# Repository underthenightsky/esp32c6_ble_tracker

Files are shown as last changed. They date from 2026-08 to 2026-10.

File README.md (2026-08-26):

# ESP32-C6 BLE Tracker — Low-Power / IMU-Gated Edition

Targets roughly **10 days on a 1000mAh battery** for an asset that
moves ~2 hrs/day, by only running BLE/WiFi when something's actually
happening — not on a fixed timer.

## Trade-off vs the other firmware variants

This version does **not** serve its own local web page. It's asleep
almost all the time, so it can't reliably answer HTTP requests — it
only pushes to your `ble_tracker_server`. If you want the
always-reachable local page, use `esp32_ble_tracker` (or
`particle_ble_tracker`) instead. You can't have both always-on local
browsability and this level of battery life on the same design — the
whole power saving comes from the radios being off almost all the
time.

## How it works

**Stationary** (the default state):
- Deep sleep, ~10 µA
- LIS3DH accelerometer armed for wake-on-motion, ~2-5 µA
- Nothing scans, nothing transmits — total draw ~15 µA
- Optional heartbeat (`HEARTBEAT_INTERVAL_S`, default 15 min): wakes
  briefly to re-push the last known position so your dashboard's
  "last seen" doesn't go stale for hours during a long stationary
  spell. Cheap since it's infrequent and skips the BLE scan entirely.

**Moving** (triggered by the IMU's motion interrupt):
- BLE scan burst (`SCAN_BURST_MS`, ~4-5s) → one-shot position estimate
- Moved ≥ `MOVE_THRESHOLD_M` (default 5m) since the last push? →
  connect WiFi, push to the server
- Didn't move that far? → skip WiFi entirely this cycle
- Re-checks every `ACTIVE_INTERVAL_S` (10s) using **light sleep**
  between cycles, which preserves the WiFi association — so a
  continuously-moving asset doesn't pay a full reconnect cost every
  10 seconds, just periodic scan+push bursts
- After `MAX_STATIONARY_CONFIRMS` (default 3, ~30s) consecutive
  checks with no real movement, drops WiFi and returns to deep,
  IMU-gated sleep

## Hardware

- ESP32-C6 dev board
- LIS3DH accelerometer breakout (I2C)
- Wiring:
  - LIS3DH SDA/SCL → ESP32-C6 I2C pins
  - LIS3DH INT1 → `IMU_INT_GPIO` in the `.ino` (default `GPIO_NUM_3`)
    — **this must be GPIO0–7**, the only pins in the C6's LP/RTC
    domain that can wake it from deep sleep. This is a hardware
    constraint of the chip, not something you can change in software.
  - LIS3DH VIN/GND → same 3.3V rail as the ESP32

No accelerometer library needed — `imu_lis3dh.h` is a small hand-
rolled I2C register driver (the LIS3DH's register map is simple and
well-documented, so this avoids pulling in a full library for what's
really about 8 register writes).

## Libraries

Just **NimBLE-Arduino** (h2zero, tested with 2.x). Everything else
(WiFi, HTTPClient, deep/light sleep) is core to the ESP32 Arduino
package — make sure you have a recent-enough `arduino-esp32` core
version with ESP32-C6 support.

## Configure

At the top of the `.ino`:

```cpp
const char* WIFI_SSID       = "YOUR_WIFI_SSID";
const char* WIFI_PASS       = "YOUR_WIFI_PASSWORD";
const char* SERVER_HOST     = "https://tracker.yourdomain.com";
const char* SERVER_API_KEY  = "changeme";      // matches server's BLE_TRACKER_API_KEY
const char* DEVICE_ID       = "esp32c6-01";    // unique per device
```

And in `imu_lis3dh.h`, `LIS3DH_ADDR` (0x18 or 0x19 depending on your
board's SA0 pin state) and `LIS3DH_MOTION_THRESHOLD` (how firm a nudge
is needed to trigger a wake — lower = more sensitive/more frequent
wakes, higher = fewer false wakes but might miss gentle movement).

## The 10-day estimate — read this before you commit to a battery

| Period | Current | Basis |
|---|---|---|
| Stationary (deep sleep + IMU armed) | ~15 µA | Published ESP32-C6 deep sleep (~10µA) + LIS3DH standby (~2-5µA) figures |
| Moving (BLE scan + WiFi, light-sleep between cycles) | ~40-50 mA avg | Estimated from published component figures — WiFi connected+modem-sleep, BLE scan burst duty-cycled over the 10s active interval |

At 2 hrs/day moving: **~85-100 mAh/day → ~10-11 days on 1000mAh**
(before real-world derating for regulator efficiency and battery
discharge curve, which typically costs another 10-15%).

**This is a directional estimate, not a bench measurement of your
specific board.** The biggest source of uncertainty is the "moving"
state average current — it depends heavily on your WiFi AP's DTIM
interval, signal strength, and exactly how well light-sleep preserves
the WiFi association on your specific core version. Before finalizing
a battery/enclosure:

1. Flash this firmware and measure actual current draw with a
   multimeter (in series with the battery) or a USB power profiler,
   in both states
2. Adjust `ACTIVE_INTERVAL_S`, `MAX_STATIONARY_CONFIRMS`,
   `HEARTBEAT_INTERVAL_S`, and `LIS3DH_MOTION_THRESHOLD` based on what
   you actually measure and how the trade-off between battery life
   and tracking responsiveness feels for your use case
3. Re-run the math with your measured numbers before ordering
   batteries for a fleet of these

## Tuning cheat sheet

| Constant | Effect of increasing it |
|---|---|
| `MOVE_THRESHOLD_M` | Fewer pushes, more battery life, coarser tracking |
| `ACTIVE_INTERVAL_S` | Fewer scan/push cycles while moving, more battery life, less responsive tracking |
| `MAX_STATIONARY_CONFIRMS` | Longer before dropping back to deep sleep after motion stops, more conservative about "really stopped" |
| `HEARTBEAT_INTERVAL_S` | Less frequent stationary check-ins, better battery life, staler "last seen" during long idle periods |
| `LIS3DH_MOTION_THRESHOLD` | Firmer nudge needed to wake, fewer false wakes, might miss gentle movement |

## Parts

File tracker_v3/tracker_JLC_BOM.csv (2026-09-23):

Comment | Designator | Footprint | JLCPCB Part #
Battery_Cell | BT1 | JST PH 2-pin, 2.00mm, right-angle THT
100n | C1,C3,C7 | 0603
10u | C2,C5,C6 | 0603
LED | D1,D2 | 0603
USB_C_Receptacle_PowerOnly_6P | J1 | USB-C receptacle, power-only 6P
DMG9926UDM-7 | Q1 | SOT-26 | C156289
0.1 | R1 | 2512
680 | R10,R8 | 0603
4.7k | R2,R3 | 0603
1.2k | R4 | 0603
5.1k | R5,R6 | 0603
100 | R7 | 0603
1k | R9 | 0603
XIAO-ESP32-C6-SMD | U1 | Seeed XIAO ESP32-C6 module
LIS3DH | U2 | LGA-16
DW01A | U3 | SOT-23-6 | C2927799
INA226AIDGSR | U4 | MSOP-10 | C49851
TP4056-42-ESOP8 | U5 | ESOP-8 | C16581

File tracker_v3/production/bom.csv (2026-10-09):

Designator | Footprint | Quantity | Value | LCSC Part #
BT1 | JST_PH_S2B-PH-K_1x02_P2.00mm_Horizontal | 1 | Battery_Cell
C1, C3, C7 | 0603 | 3 | 100n
C2, C5, C6 | 0603 | 3 | 10u
D1, D2 | 0603 | 2 | LED
J1 | USB_C_Receptacle_GCT_USB4125-xx-x-0190_6P_TopMnt_Horizontal | 1 | USB_C_Receptacle_PowerOnly_6P
J2, J3 | HARWIN_P70-7000045 | 2 | P70-7000045
Q1 | SOT-26_DIO | 1 | DMG9926UDM-7
R1 | 2512 | 1 | 0.1
R10, R8 | 0603 | 2 | 680
R2, R3 | 0603 | 2 | 4.7k
R4 | 0603 | 1 | 1.2k
R5, R6 | 0603 | 2 | 5.1k
R7 | 0603 | 1 | 100
R9 | 0603 | 1 | 1k
TP1, TP2, TP3, TP4, TP5, TP6, TP7, TP8 | TestPoint_Pad_D1.0mm | 8 | TestPoint
U1 | XIAO-ESP32-C6-DIP | 1 | XIAO-ESP32-DIP
U2 | LGA-16_3x3mm_P0.5mm_LayoutBorder3x5y | 1 | LIS3DH
U3 | SOT-23-6 | 1 | DW01A
U4 | MSOP-10_3x3mm_P0.5mm | 1 | INA226AIDGSR | C49851
U5 | SOIC-8-1EP_3.9x4.9mm_P1.27mm_EP2.41x3.3mm_ThermalVias | 1 | TP4056-42-ESOP8

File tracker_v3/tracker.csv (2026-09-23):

Designator | Footprint | Quantity | Designation | Supplier and ref
BT1 | JST_PH_S2B-PH-K_1x02_P2.00mm_Horizontal | 1 | Battery_Cell
C1, C3, C7 | C_0603_1608Metric | 3 | 100n
C2, C5, C6 | C_0603_1608Metric | 3 | 10u
D1, D2 | LED_0603_1608Metric | 2 | LED
J1 | USB_C_Receptacle_GCT_USB4125-xx-x-0190_6P_TopMnt_Horizontal | 1 | USB_C_Receptacle_PowerOnly_6P
Q1 | SOT-26_DIO | 1 | DMG9926UDM-7
R1 | R_2512_6332Metric | 1 | 0.1
R2, R3 | R_0603_1608Metric | 2 | 4.7k
R4 | R_0603_1608Metric | 1 | 1.2k
R5, R6 | R_0603_1608Metric | 2 | 5.1k
R7 | R_0603_1608Metric | 1 | 100
R8, R10 | R_0603_1608Metric | 2 | 680
R9 | R_0603_1608Metric | 1 | 1k
U1 | XIAO-ESP32-C6-SMD | 1 | XIAO-ESP32-C6-SMD
U2 | LGA-16_3x3mm_P0.5mm_LayoutBorder3x5y | 1 | LIS3DH
U3 | SOT-23-6 | 1 | DW01A
U4 | MSOP-10_3x3mm_P0.5mm | 1 | INA226AIDGSR
U5 | SOIC-8-1EP_3.9x4.9mm_P1.27mm_EP2.41x3.3mm_ThermalVias | 1 | TP4056-42-ESOP8

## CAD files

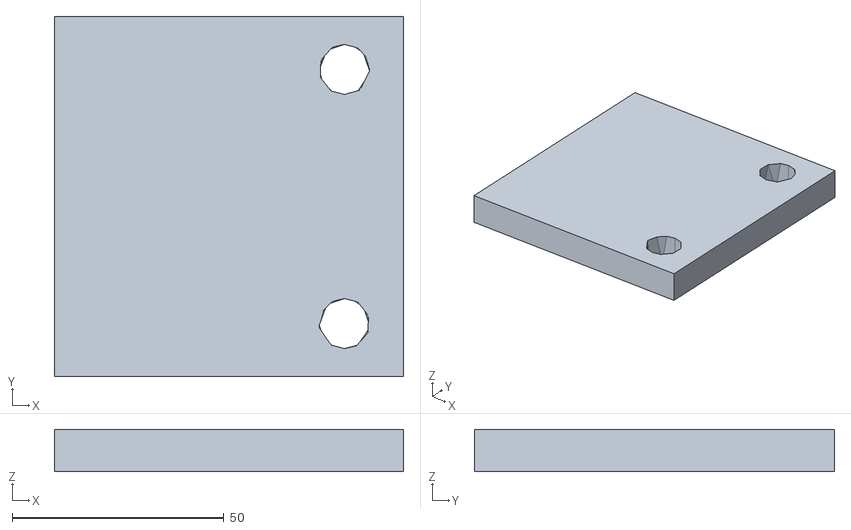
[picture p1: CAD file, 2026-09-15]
tracker_v3/OBJ_INA226-CJMCU-226-BLUE_2026-09-15/OBJ_INA226 CJMCU-226 BLUE.obj
82.5 x 85.0 x 10.0

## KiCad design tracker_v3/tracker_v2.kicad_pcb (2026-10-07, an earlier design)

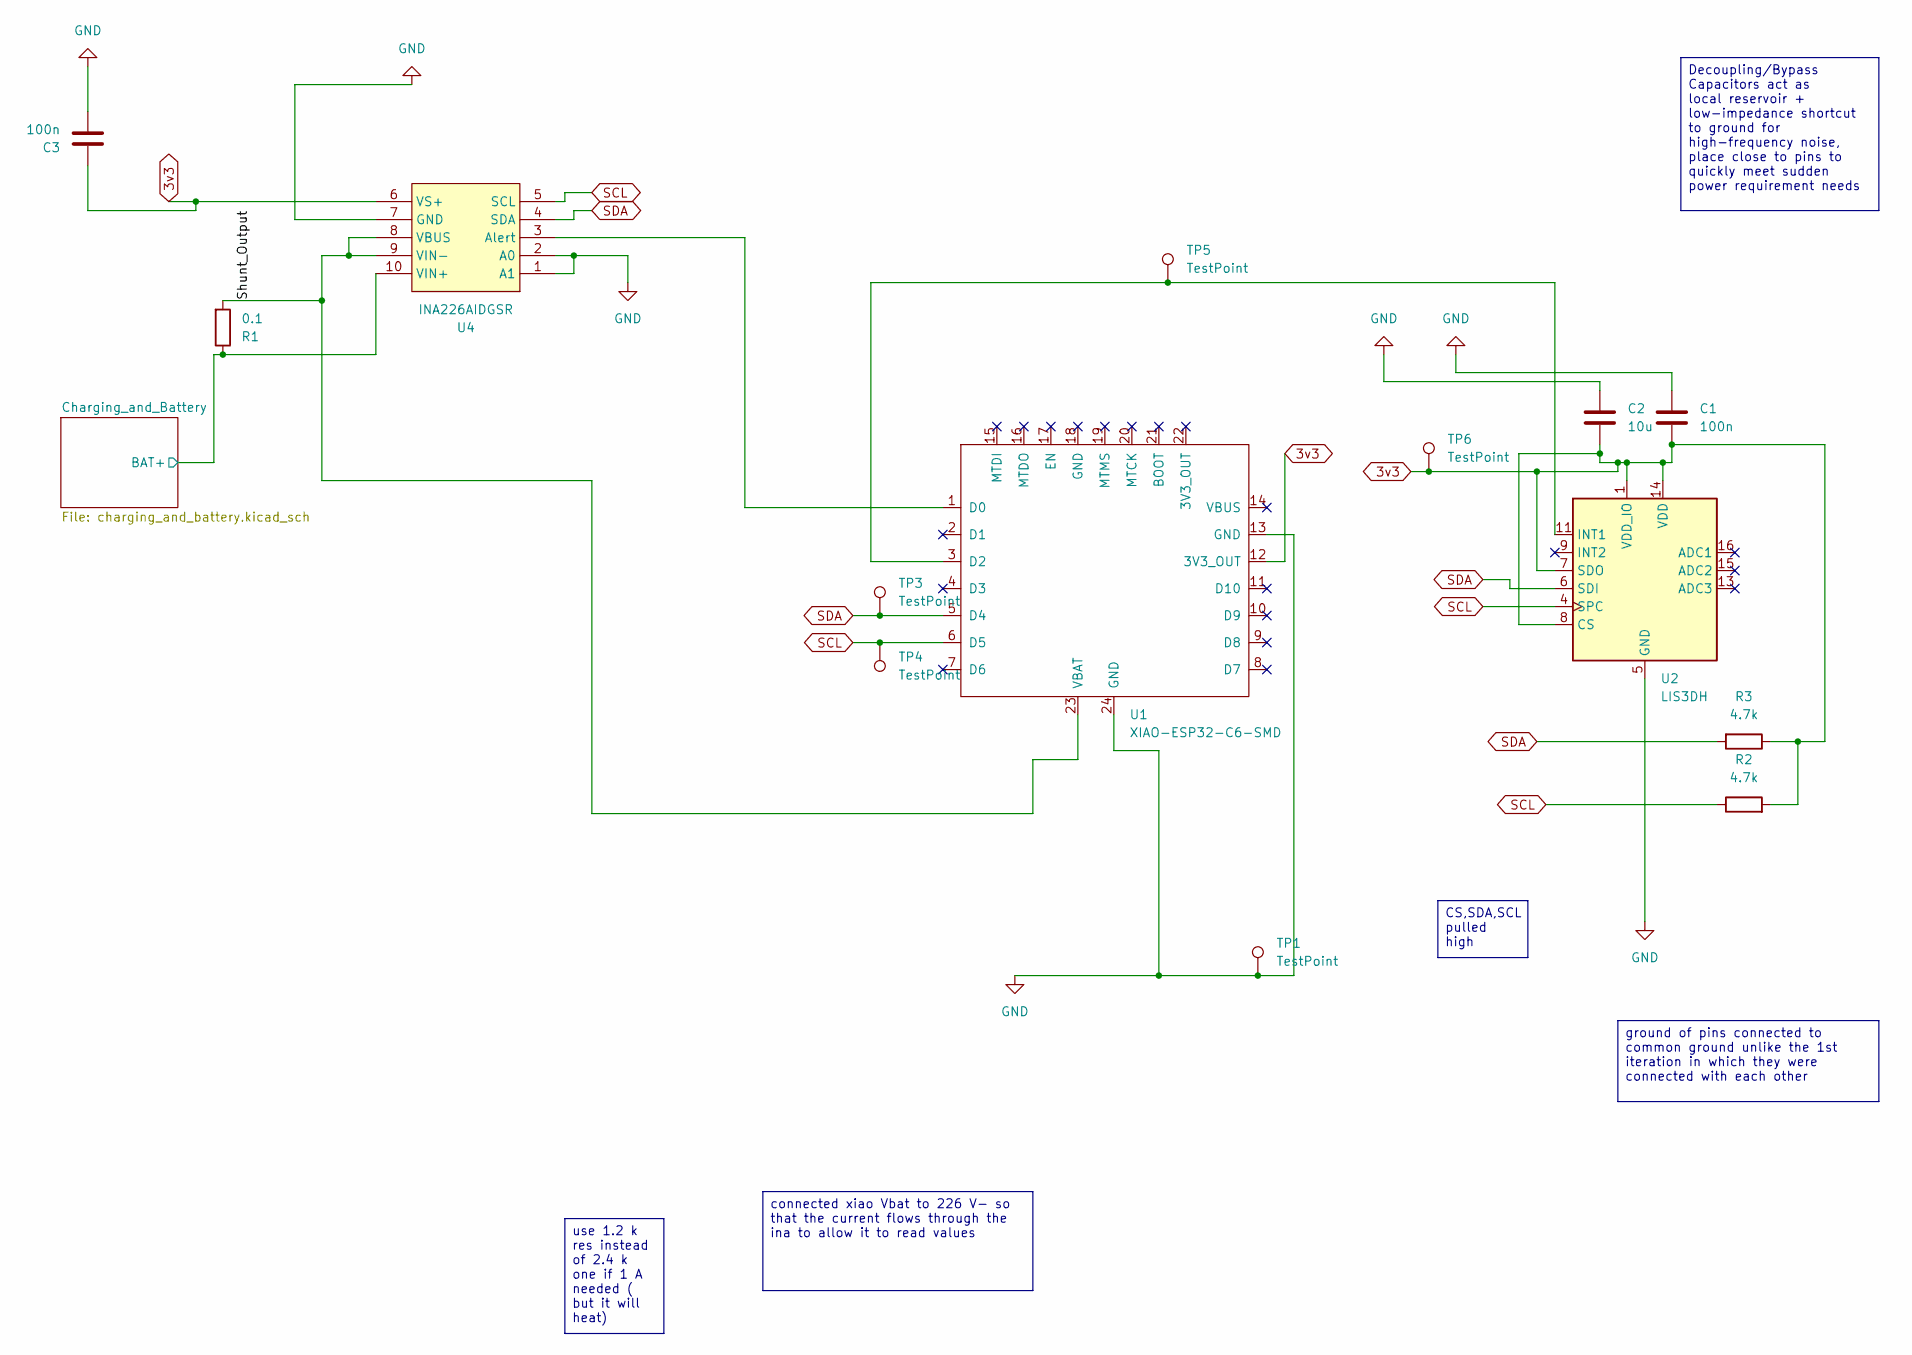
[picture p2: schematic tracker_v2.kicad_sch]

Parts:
C1, C3: 100n; C_0603_1608Metric
C2: 10u; C_0603_1608Metric
R1: 0.1; R_2512_6332Metric
R2, R3: 4.7k; R_0603_1608Metric
TP1, TP3, TP4, TP5, TP6: TestPoint; TestPoint_Pad_D1.0mm
U1: XIAO-ESP32-C6-SMD
U2: LIS3DH; LGA-16_3x3mm_P0.5mm_LayoutBorder3x5y
U4: INA226AIDGSR; MSOP-10_3x3mm_P0.5mm; MPN INA226AIDGSR; LCSC Part C49851

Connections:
3v3: C1.2, C2.2, C3.1, R2.2, R3.1, TP6.1 (1_1), U1.12 (3V3_OUT), U2.1 (VDD_IO), U2.7 (SDO), U2.8 (CS), U2.14 (VDD), U4.6 (VS+)
/Charging_and_Battery/BAT+: R1.1, U4.10 (VIN+); also elsewhere on the board
/Shunt_Output: R1.2, U1.23 (VBAT), U4.8 (VBUS), U4.9 (VIN-)
GND: C1.1, C2.1, C3.2, TP1.1 (1_1), U1.13 (GND), U1.24 (GND), U2.5 (GND), U2.10 (GND), U2.12 (GND), U4.1 (A1), U4.2 (A0), U4.7 (GND); also elsewhere on the board
unnamed: U1.1 (D0), U4.3 (Alert)
unnamed: TP5.1 (1_1), U1.3 (D2), U2.11 (INT1)
SCL: R2.1, TP4.1 (1_1), U1.6 (D5), U2.4 (SPC), U4.5 (SCL)
SDA: R3.2, TP3.1 (1_1), U1.5 (D4), U2.6 (SDI), U4.4 (SDA)

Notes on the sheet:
CS,SDA,SCL pulled high
connected xiao Vbat to 226 V- so that the current flows through the ina to allow it to read values
ground of pins connected to common ground unlike the 1st iteration in which they were connected with each other
Decoupling/Bypass Capacitors act as local reservoir + low-impedance shortcut to ground for high-frequency noise, place close to pins to quickly meet sudden power requirement needs
use 1.2 k res instead of 2.4 k one if 1 A needed ( but it will heat)

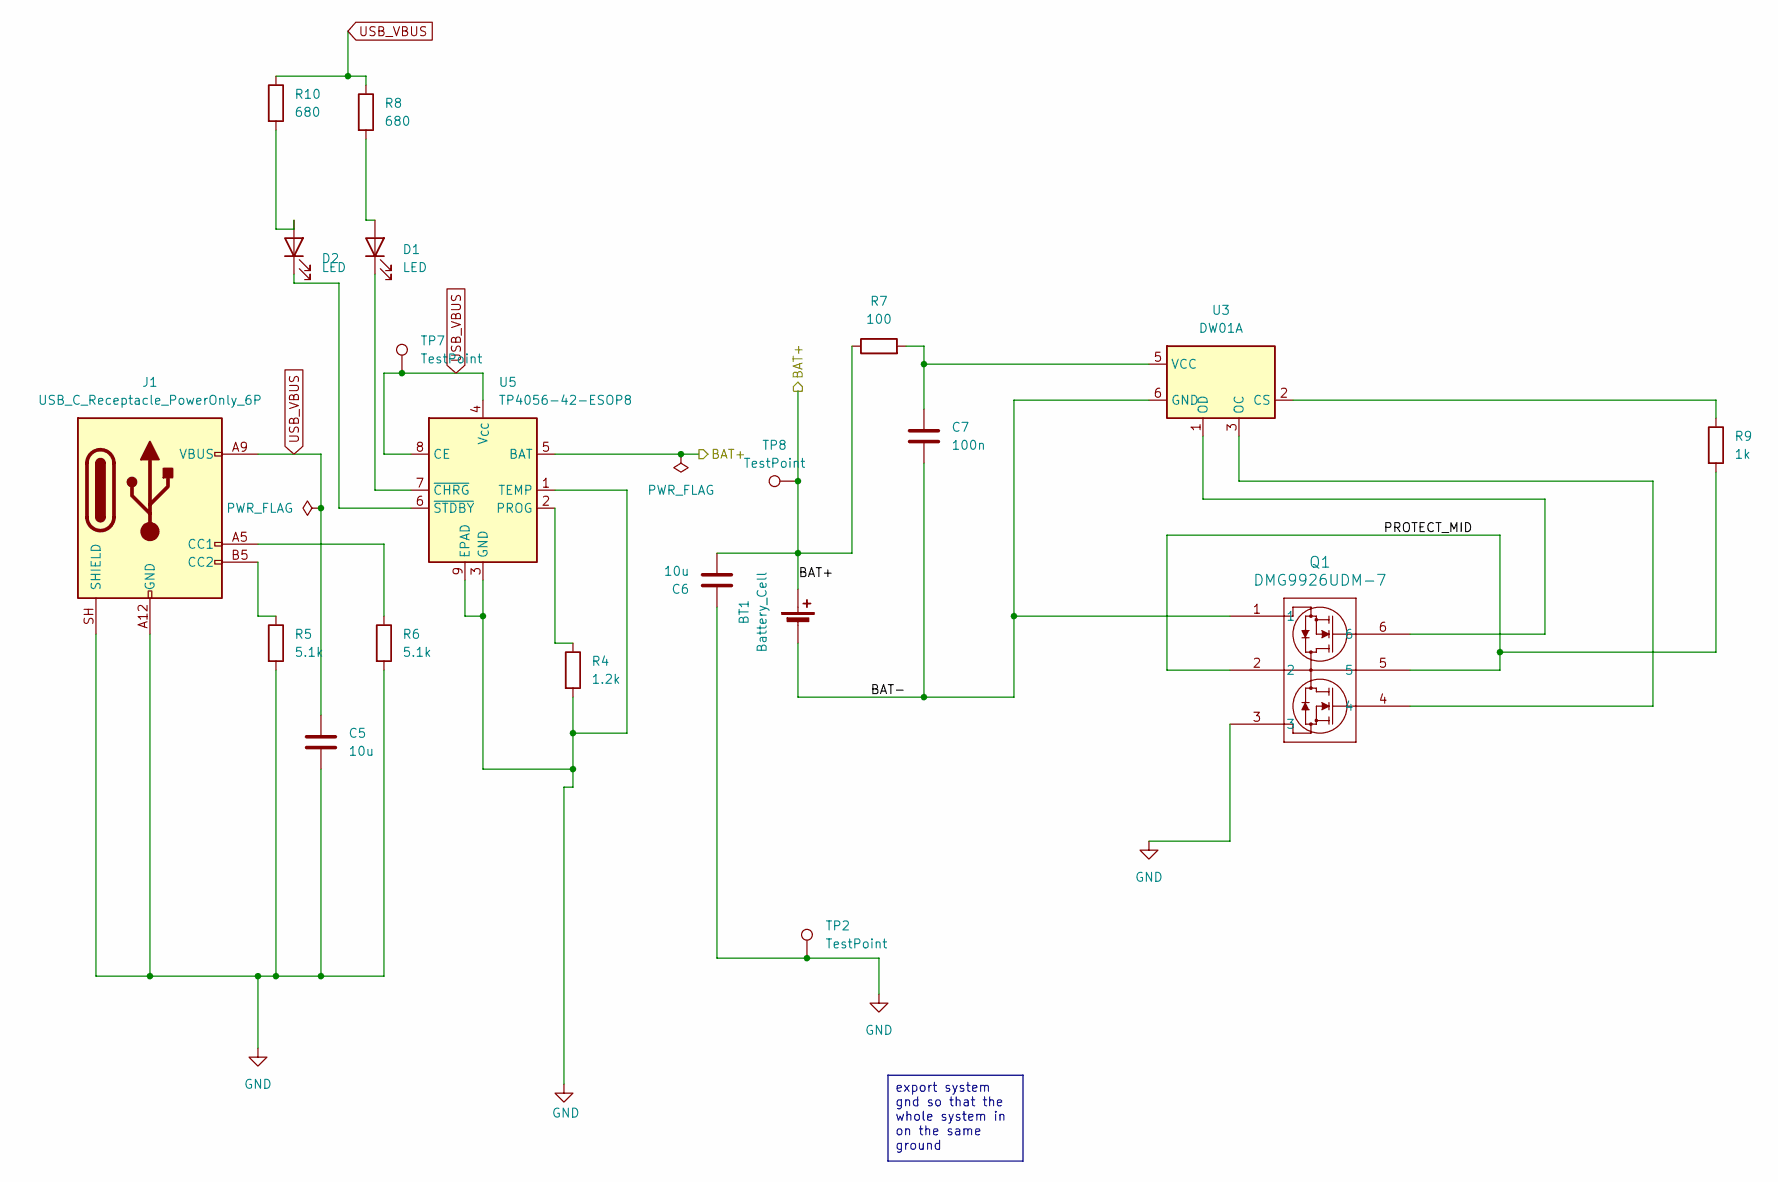
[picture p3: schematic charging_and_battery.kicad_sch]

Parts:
BT1: Battery_Cell; JST_PH_S2B-PH-K_1x02_P2.00mm_Horizontal
C5, C6: 10u; C_0603_1608Metric
C7: 100n; C_0603_1608Metric
D1, D2: LED; LED_0603_1608Metric
J1: USB_C_Receptacle_PowerOnly_6P; USB_C_Receptacle_GCT_USB4125-xx-x-0190_6P_TopMnt_Horizontal
Q1: DMG9926UDM-7; SOT-26_DIO
R4: 1.2k; R_0603_1608Metric
R5, R6: 5.1k; R_0603_1608Metric
R7: 100; R_0603_1608Metric
R8, R10: 680; R_0603_1608Metric
R9: 1k; R_0603_1608Metric
TP2, TP7, TP8: TestPoint; TestPoint_Pad_D1.0mm
U3: DW01A; SOT-23-6
U5: TP4056-42-ESOP8; SOIC-8-1EP_3.9x4.9mm_P1.27mm_EP2.41x3.3mm_ThermalVias

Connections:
/Charging_and_Battery/BAT+: BT1.1 (+), C6.2, R7.1, TP8.1 (1_1), U5.5 (BAT); also elsewhere on the board
/Charging_and_Battery/BAT-: BT1.2 (-), C7.2, Q1.1, U3.6 (GND)
/Charging_and_Battery/PROTECT_MID: Q1.2, Q1.5, R9.2
GND: C5.2, C6.1, J1.A12 (GND), J1.B12 (GND), J1.SH (SHIELD), Q1.3, R4.2, R5.2, R6.2, TP2.1 (1_1), U5.1 (TEMP), U5.3 (GND), U5.9 (EPAD); also elsewhere on the board
unnamed: D1.2 (A), R8.2
unnamed: D1.1 (K), U5.7 (~CHRG)
unnamed: D2.2 (A), R10.2
unnamed: D2.1 (K), U5.6 (~STDBY)
unnamed: J1.A5 (CC1), R6.1
unnamed: J1.B5 (CC2), R5.1
unnamed: R9.1, U3.2 (CS)
unnamed: Q1.4, U3.3 (OC)
unnamed: Q1.6, U3.1 (OD)
unnamed: C7.1, R7.2, U3.5 (VCC)
unnamed: R4.1, U5.2 (PROG)
USB_VBUS: C5.1, J1.A9 (VBUS), J1.B9 (VBUS), R8.1, R10.1, TP7.1 (1_1), U5.4 (V_{CC}), U5.8 (CE)

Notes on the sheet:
export system gnd so that the whole system in on the same ground

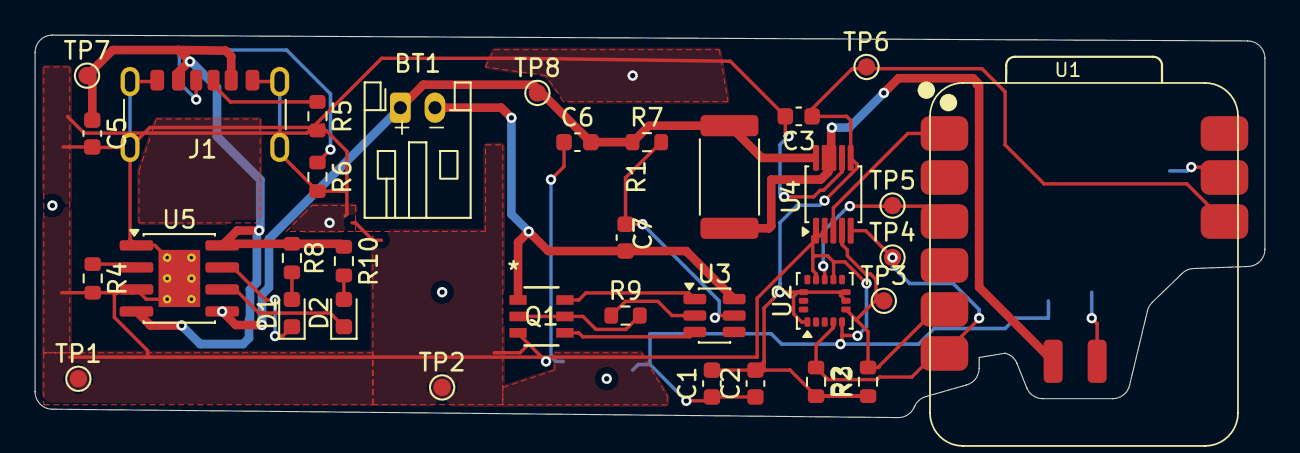
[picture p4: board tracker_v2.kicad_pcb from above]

Board: 2 copper layers, 71.0 x 22.1 mm, 34 parts (0 on the bottom side), 22 nets.

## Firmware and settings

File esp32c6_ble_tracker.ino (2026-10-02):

/*
  MotionWakeSimpleTest.ino — minimal wake-on-motion -> BLE scan -> WiFi push
  (power-optimized variant)

  Deliberately simple, for testing the pipeline end to end:
    1. Deep sleep. LIS3DH wakes it on motion (D2).
    2. On wake: scan for nearby BLE devices for a few seconds (this
       will pick up your phone if its Bluetooth is on — phones usually
       show up as an anonymous rotating address rather than a name,
       which is fine, you can still watch its RSSI change as you move
       it closer/farther. If you want it to show up with a real name,
       install a free app like "nRF Connect" and use its BLE
       peripheral/advertiser feature to broadcast a named signal).
    3. Connect WiFi, POST the scan results (device list + one fresh
       accel reading) to your laptop as one JSON blob.
    4. Go straight back to deep sleep. No loop, no re-checking, no
       "did it really stop moving" state machine — one wake, one
       scan, one push, one sleep. If it's not going back to sleep,
       the bug is much easier to find in this shape than in the full
       tracker's active-loop logic.

  No beacons.h / estimator_types.h dependency — this doesn't do
  position triangulation at all, just reports what it saw.

  Wiring (confirmed): SDA->D4 (GPIO22), SCL->D5 (GPIO23),
  LIS3DH I1 -> D2 (GPIO2, in the C6's LP/RTC wake domain).
  Libraries: SparkFun LIS3DH, NimBLE-Arduino.

  --- POWER CHANGES vs. original ---
  1. LIS3DH ODR dropped 10Hz -> 1Hz (CTRL_REG1 0x2F -> 0x1F). The
     LPen (low-power) bit was already set, so this doesn't change
     operating mode, only sample rate. Adds up to ~1s of wake
     latency worst-case; bump back to 0x2F (10Hz) if that feels
     sluggish in testing.
  2. Added isolateUnusedPins(): on the ESP32-C6, only GPIO0-7 are in
     the LP_IO domain that stays powered for GPIO wakeup (RTC_PERIPH
     stays on for D2), so those are the only pins where a stray
     pull can leak current in deep sleep. D0/D1 are unused here, so
     they get isolated. D3/D6-D10 live in the HP GPIO domain, which
     is fully powered off in deep sleep regardless of firmware —
     nothing to isolate there.
  3. No change needed on the LIS3DH side beyond ODR: LPen was
     already enabled, and full power-down isn't usable since it
     would also disable the wake interrupt.
  4. Added phase timing: millis() timestamps at each stage boundary,
     printed as a table right before deep sleep. Everything from
     "sensor read" onward is measured exactly. Wake+boot latency
     (interrupt -> setup() actually running) can't be measured this
     way -- millis() itself resets at boot -- so WAKE_MARKER_PIN
     (D6, unused) is driven HIGH as the very first line of setup()
     and LOW right before sleep, so that latency shows up directly
     on a scope or power profiler (e.g. Nordic PPK2) against the
     current trace instead of being guessed at.

  Note: XIAO ESP32C6 boards measure ~15uA bare deep-sleep current
  (dominated by the onboard LDO's own quiescent draw per community
  teardown measurements) — the LIS3DH in low-power mode typically
  adds a few uA on top of that per its datasheet. These firmware
  changes get you close to that floor; going lower generally means
  a different/lower-Iq regulator on the board itself, which is a
  hardware change, not a firmware one.
*/

#include "SparkFunLIS3DH.h"
#include "Wire.h"
#include <esp_sleep.h>
#include <WiFi.h>
#include <NimBLEDevice.h>
#include <HTTPClient.h>
#include "driver/rtc_io.h"
#include <INA226_WE.h>
#include "beacons.h"
#include "estimator_types.h"
#include <sys/time.h>
#include "power_meter.h"

// ── WiFi / local test server ────────────────────────────────────────
const char* WIFI_SSID       = "Airtel_Iwayplus";
const char* WIFI_PASS       = "sulpyawi";
const char* SERVER_HOST = "https://esp32c6-ble-tracker.onrender.com";  // was .250
const char* SERVER_API_KEY  = "f4d0cb00-dbf5-11f0-bd35-dd4e9bf51317";
const char* DEVICE_ID       = "esp32-01";

#define LIS3DH_MOTION_THRESHOLD 0x6  // MIDDLE GROUND: ~96mg ( 0x6), a firm tap/nudge triggers it,
                                        // but not every tiny desk vibration.

                                        // Production value was 0x10 (~256mg). Raise back toward
                                        // that once testing is done, if it's too sensitive in use.

// CTRL_REG1: ODR[3:0] | LPen | Zen | Yen | Xen
//   0x2F = 10Hz, low-power mode, all axes  (previous value)
//   0x1F =  1Hz, low-power mode, all axes  (current — lower sample rate,
//           same low-power mode, adds up to ~1s worst-case wake latency)
#define LIS3DH_CTRL_REG1_VALUE 0x1F

// INA226 connection code
// I2C address for INA226 is 0x40
#define I2C_INA226_ADDRESS 0x40

// Timing instrumentation ----------------------------------------------------
// WAKE_MARKER_PIN is toggled HIGH as the very first line of setup() and LOW
// right before esp_deep_sleep_start(). It's unused elsewhere on this board,
// so probing it with a scope or power profiler lines up the exact moment
// code execution starts against the current-draw trace -- the only way to
// see true wake+boot latency, since millis() resets at boot and can't
// measure anything before setup() runs.
#define WAKE_MARKER_PIN D6

#define SCAN_MS 1000              // how long to listen for BLE devices, set to 1500 or higher (not above 2500 to avoid high power drain) for better chances of locating the beacons and calculating the position

const float TEMP =3.0f;
static const int TOP_N =3;
static const float ALPHA_W =0.55f;
static const float BONUS =0.5f;
static const int MIN_RSSI = -110;
// not sure why there is max signal strength limit
// shouldnt stronger signal lead to more confident result ?
static const int MAX_RSSI =-55;

LIS3DH SensorOne(I2C_MODE, 0x19);
RTC_DATA_ATTR uint32_t g_bootCount = 0;
// Persistent estimator memory
// (so that we can compare currently estimated position with previous poistion and 
// decide wether to send the data or not  )
RTC_DATA_ATTR bool g_haveEma = false;
RTC_DATA_ATTR float g_emaX=0,g_emaY=0;
RTC_DATA_ATTR int8_t g_top2[2] {-1,-1};
RTC_DATA_ATTR uint32_t g_tooCloseCount =0;

static const float MOVE_THRESHOLD_M =2.0f;
// last position actually pushed to the server - distict
//from g_emaX/g_emaY above. This is what MOVE_THRESHOLD_M compares against
RTC_DATA_ATTR bool g_havePub = false;
RTC_DATA_ATTR float g_pubX=0, g_pubY =0;

// to check number of wakeups vs number of wifi pushes
RTC_DATA_ATTR uint32_t g_wakeCount = 0;
RTC_DATA_ATTR uint32_t g_noBeaconCount = 0;
RTC_DATA_ATTR uint32_t g_wifiFailCount = 0;
RTC_DATA_ATTR uint32_t g_pushOkCount = 0;

// Per-cycle phase timestamps. Plain (non-RTC) globals on purpose -- deep
// sleep is a full chip reset, so these zero out every boot, giving a clean
// per-cycle timing log instead of an accumulating total.
static unsigned long g_tBoot = 0;
static unsigned long g_tSensorReady = 0;
static unsigned long g_tBleDone = 0;
static unsigned long g_tPosDone = 0;
static unsigned long g_tWifiDone = 0;      // 0 if WiFi step was skipped/never finished
static unsigned long g_tPushDone = 0;      // 0 if push never happened this cycle

// Single Burst aggregated beacon readings
struct Agg{
  bool present = false;
  int peak = -200;
  int n =0;
  float pen_peak =0;
  float score=0;
};

static Agg g_agg[NUM_BEACONS];

// we are making our own class called ScanCallbacks
class ScanCallbacks : public NimBLEScanCallbacks {
  void onResult(const NimBLEAdvertisedDevice* dev) override {

  std::string name = dev->getName();
  // now we get the rssi and later return if the value exceeds the limits
  int rssi = dev->getRSSI();

  if(rssi <= MIN_RSSI ){
    return;
  }
  //now checking against the known beacons name
  for(int i =0; i<NUM_BEACONS;i++){
    if(name == BEACONS[i].name){
      g_agg[i].present = true;
      if(rssi > g_agg[i].peak){
        g_agg[i].peak = rssi;
      }

      g_agg[i].n++ ;
      return;
    }
  }
  }
};
static ScanCallbacks g_scanCallbacks;

// ── LIS3DH motion-interrupt setup (same as the confirmed-working test) ─
static void armMotionInterrupt() {
  SensorOne.writeRegister(LIS3DH_CTRL_REG1, LIS3DH_CTRL_REG1_VALUE);
  SensorOne.writeRegister(LIS3DH_CTRL_REG2, 0x2F);

  // Reading REFERENCE resets the HPF's internal reference to whatever
  // the current (post-filter) value is. Without this, the filter needs
  // several ODR cycles to settle after being (re)enabled, and during
  // that window it can output a transient big enough to cross the
  // threshold by itself -- which looks exactly like a phantom wake
  // with the board sitting perfectly still.
  uint8_t ref;
  SensorOne.readRegister(&ref, LIS3DH_REFERENCE);
  delay(150); // let the filter fully settle before arming/clearing
// was 100ms for 10Hz, at 1Hz we set 1000ms
  SensorOne.writeRegister(LIS3DH_CTRL_REG3, 0x40);
  SensorOne.writeRegister(LIS3DH_CTRL_REG4, 0x00);
  SensorOne.writeRegister(LIS3DH_CTRL_REG5, 0x08);
  SensorOne.writeRegister(LIS3DH_INT1_THS, LIS3DH_MOTION_THRESHOLD);
  SensorOne.writeRegister(LIS3DH_INT1_DURATION, 0x00);
  SensorOne.writeRegister(LIS3DH_INT1_CFG, 0x2A);
}

static void clearMotionInterrupt() {
  uint8_t dummy;
  // Read INT1_SRC in a loop until physical pin drops LOW
  for (int i = 0; i < 10; i++) {
    SensorOne.readRegister(&dummy, LIS3DH_INT1_SRC);
    if (digitalRead(D2) == LOW) break;
    delay(20);
  }
}

// Isolate the GPIOs we don't use that actually matter for deep-sleep
// current on the C6: GPIO0-7 are the LP_IO pins whose power domain
// stays alive for our D2 (GPIO2) wake source. D0 (GPIO0) and D1
// (GPIO1) are unused here, so disconnect their input/output/pull
// circuitry before sleeping. D2 itself is left alone (it's the wake
// pin). D3/D6-D10 (GPIO16-21) are outside the LP_IO range — they sit
// in the HP GPIO domain, which is fully powered off in deep sleep on
// this chip, so there's no isolate() call for them and none needed.
static void isolateUnusedPins() {
  rtc_gpio_isolate(GPIO_NUM_0);  // D0, unused
  rtc_gpio_isolate(GPIO_NUM_1);  // D1, unused
}

// for checking if the chip is still moving or not
static const uint32_t REST_TIMER_S =15;
static const float MOTION_SAMPLE_COUNT =4;
static const float MOTION_STILL_DELTA_G =0.15f;
static bool isCurrentlyMoving(){
float mag = 0;
float minMag = 999.0f;
float maxMag =0.0f;
  for (int i = 0; i < MOTION_SAMPLE_COUNT; i++) {
    float ax = SensorOne.readFloatAccelX();
    float ay = SensorOne.readFloatAccelY();
    float az = SensorOne.readFloatAccelZ();
    mag = sqrtf(ax*ax + ay*ay + az*az);
    if (mag < minMag) minMag = mag;
    if (mag > maxMag) maxMag = mag;
    delay(100);   // spread samples out a bit rather than reading back-to-back
  }
float deltaMag = maxMag - minMag;
  Serial.printf("Motion check: min=%.3fg, max=%.3fg (delta=%.3fg)\n", minMag, maxMag, deltaMag);

  return deltaMag > MOTION_STILL_DELTA_G;

}
static void doBleScan() {
  
  for(int i =0; i<NUM_BEACONS;i++){
    g_agg[i]= Agg();
  }

  NimBLEDevice::init("XIAO-C6-Tracker");
  // Give NimBLE host a brief moment to sync after deep sleep
unsigned long startSync = millis();

  NimBLEScan* scan = NimBLEDevice::getScan();
  scan->setScanCallbacks(&g_scanCallbacks, false);
  scan->setActiveScan(true);
  scan->setInterval(100);
  scan->setWindow(99);
  // NimBLE-Arduino v2.x note: start() is NON-blocking -- it returns almost
  // immediately and the scan continues in the background. Calling deinit()
  // right after start() (as the original code did) tears the scan down
  // after only tens of ms, which is why beacons were never found. getResults()
  // is the v2.x function that actually blocks for the given duration; the
  // registered onResult() callback still fires per-device exactly as before.
  scan->getResults(SCAN_MS, false);   // blocks for SCAN_MS milliseconds
  meterTick();
  NimBLEDevice::deinit(true);
}
static void sleepUntilTimerOnly(uint32_t seconds){
  esp_sleep_enable_timer_wakeup((uint64_t)seconds*1000000ULL);

  if(WiFi.getMode()!= WIFI_MODE_NULL){
    WiFi.disconnect(true);
    WiFi.mode(WIFI_OFF);
  }
  meterTick();
   if(g_inaOk){
    ina226.powerDown();
  }
  gettimeofday(&g_sleepEnter,NULL);
  g_haveSleepStamp=true;

  meterPrepareSleep();

  isolateUnusedPins();
 unsigned long tTeardownDone = millis();
 printTimingSummary(tTeardownDone);
 digitalWrite(WAKE_MARKER_PIN,LOW);
 Serial.println("Still moving, sleeping for 25 sec, motion won't wake the chip");
 Serial.flush();
  esp_deep_sleep_start();  
}

static void sleepUntilMotionOnly(){
  // settled sleep: only the LIS3DH interrupt on D2 wakes it up 
  armMotionInterrupt();
  clearMotionInterrupt();
  meterTick();
   if(g_inaOk){
    ina226.powerDown();
  }
  gettimeofday(&g_sleepEnter,NULL);
  g_haveSleepStamp=true;

  pinMode(D2,INPUT);
  esp_deep_sleep_enable_gpio_wakeup((1ULL <<D2),ESP_GPIO_WAKEUP_GPIO_HIGH);
  if(WiFi.getMode() != WIFI_MODE_NULL){
    WiFi.disconnect(true);
    WiFi.mode(WIFI_OFF);
  }
  isolateUnusedPins();
  unsigned long tTeardownDone = millis();
  printTimingSummary(tTeardownDone);
  digitalWrite(WAKE_MARKER_PIN,LOW);
  Serial.println("settled, wakeup on next motion");
  Serial.flush();
  esp_deep_sleep_start();
}
static bool calculatePosition(EstResult& out) {
  int8_t order[NUM_BEACONS];
  int nPresent = 0;

  for (int i = 0; i < NUM_BEACONS; i++) {
    if (!g_agg[i].present) continue;
    float penalty = (g_agg[i].n == 1) ? -4.0f : (g_agg[i].n == 2 ? -2.0f : 0.0f);
    g_agg[i].pen_peak = g_agg[i].peak + penalty;
    g_agg[i].score = g_agg[i].pen_peak + ((i == g_top2[0] || i == g_top2[1]) ? BONUS : 0.0f);
    order[nPresent++] = i;
  }
  if (nPresent == 0) return false;

  // Insertion sort by score descending
  for (int a = 1; a < nPresent; a++) {
    int8_t key = order[a];
    float keyScore = g_agg[key].score;
    int b = a - 1;
    while (b >= 0 && g_agg[order[b]].score < keyScore) {
      order[b + 1] = order[b];
      b--;
    }
    order[b + 1] = key;
  }

  int topN = min(TOP_N, nPresent);
  float maxPen = g_agg[order[0]].pen_peak;
  float weights[8];
  float wsum = 0;

  for (int i = 0; i < topN; i++) {
    weights[i] = expf((g_agg[order[i]].pen_peak - maxPen) / TEMP);
    wsum += weights[i];
  }
  for (int i = 0; i < topN; i++) weights[i] /= wsum;

  float rx = 0, ry = 0;
  for (int i = 0; i < topN; i++) {
    rx += weights[i] * BEACONS[order[i]].lx;
    ry += weights[i] * BEACONS[order[i]].ly;
  }

  // Smooth position across deep sleep cycles using persistent RTC state
  if (!g_haveEma) {
    g_emaX = rx; g_emaY = ry; g_haveEma = true;
  } else {
    g_emaX = ALPHA_W * rx + (1.0f - ALPHA_W) * g_emaX;
    g_emaY = ALPHA_W * ry + (1.0f - ALPHA_W) * g_emaY;
  }

  g_top2[0] = order[0];
  g_top2[1] = (nPresent > 1) ? order[1] : (int8_t)-1;

  out.x = g_emaX; out.y = g_emaY;
  out.b1Name = BEACONS[order[0]].name;
  out.b1Rssi = g_agg[order[0]].peak;
  out.nBeacons = nPresent;
  out.conf = (nPresent >= 3) ? "high" : "low";
  out.motion = "walking";
  return true;
}

static bool connectWiFi() {
  WiFi.mode(WIFI_STA);
  WiFi.begin(WIFI_SSID, WIFI_PASS);
  unsigned long t0 = millis();
  while (WiFi.status() != WL_CONNECTED && millis() - t0 < 8000){
    meterTick();
    delay(50);
  } 
  return WiFi.status() == WL_CONNECTED;
}
static void num(char* out, size_t n, float v, const char* fmt) {
  if (isnan(v)) snprintf(out, n, "null"); else snprintf(out, n, fmt, v);
}

// the max time that the post will try without response is 5 seconds
static void pushPositionToServer(const EstResult& r, float ax, float ay, float az,
                                 const PowerReading& pi, const PowerReading& pw) {
  char vb[16], ii[16], vw[16], iw[16];
  jnum(vb, sizeof(vb), pi.battV,     "%.3f");
  jnum(ii, sizeof(ii), pi.currentMa, "%.1f");
  jnum(vw, sizeof(vw), pw.battV,     "%.3f");
  jnum(iw, sizeof(iw), pw.currentMa, "%.1f");

  char buf[520];
  snprintf(buf, sizeof(buf),
    "{\"device_id\":\"%s\",\"x\":%.2f,\"y\":%.2f,\"conf\":\"%s\","
    "\"motion\":\"%s\",\"b1\":\"%s\",\"b1_rssi\":%d,\"n\":%d,"
    "\"accel\":{\"x\":%.2f,\"y\":%.2f,\"z\":%.2f},"
    "\"vbat\":%s,\"i_idle_ma\":%s,\"vbat_wifi\":%s,\"i_wifi_ma\":%s,"
    "\"used_mah\":%.3f,\"slept_s\":%.0f}",
    DEVICE_ID, r.x, r.y, r.conf, r.motion, r.b1Name, r.b1Rssi, r.nBeacons, ax, ay, az,
    vb, ii, vw, iw, g_usedMah, g_sleptS);

  HTTPClient http;
  String url = String(SERVER_HOST) + "/api/push?api_key=" + String(SERVER_API_KEY);
  if (http.begin(url)) {
    http.addHeader("Content-Type", "application/json");
    http.addHeader("X-API-Key", SERVER_API_KEY);
    http.POST(String(buf));
    http.end();
  }
}

// Prints the per-cycle phase breakdown. Called right before deep sleep,
// once all of this cycle's timestamps are known. tTeardownDone is passed
// in rather than read from a global since it's taken right at the call site.
static void printTimingSummary(unsigned long tTeardownDone) {
  Serial.println("\n--- Phase timing (ms) ---");
  Serial.printf("Sensor init+read : %4lu\n", g_tSensorReady - g_tBoot);
  Serial.printf("BLE scan         : %4lu\n", g_tBleDone - g_tSensorReady);
  Serial.printf("Position calc    : %4lu\n", g_tPosDone - g_tBleDone);

  unsigned long lastStamp = g_tPosDone;
  if (g_tWifiDone > 0) {
    Serial.printf("WiFi connect     : %4lu\n", g_tWifiDone - g_tPosDone);
    lastStamp = g_tWifiDone;
    if (g_tPushDone > 0) {
      Serial.printf("HTTP POST        : %4lu\n", g_tPushDone - g_tWifiDone);
      lastStamp = g_tPushDone;
    };
    
  } else {
    Serial.println("WiFi connect     : skipped (no beacons this cycle)");
  }

  Serial.printf("Teardown+isolate : %4lu\n", tTeardownDone - lastStamp);
  Serial.printf("Total setup() time: %4lu ms\n", tTeardownDone - g_tBoot);
  Serial.println("(wake+boot latency before setup() started is NOT included");
  Serial.println(" here -- probe WAKE_MARKER_PIN against the current trace");
  Serial.println(" on a scope/power profiler to see that part.)");
}
// static void goToSleep(bool isMoving) {
//   pinMode(D2, INPUT_PULLDOWN);

//   if (isMoving) {
//     // ── MODE 1: MOVING (Timer-Only Sleep) ─────────────────────────────
//     // Wakes ONLY when 25 seconds elapse. Motion events are ignored.
//     esp_sleep_enable_timer_wakeup((uint64_t)REST_TIMER_S * 1000000ULL);
//     Serial.println("State: MOVING -> Deep sleep for 25s (Timer wake ONLY, motion ignored).");
//   } 
//   else {
//     // ── MODE 2: SETTLED (Motion-Only Sleep) ───────────────────────────
//     // Wakes ONLY on LIS3DH interrupt (D2 HIGH). Timer is NOT armed.
//     armMotionInterrupt();
//     clearMotionInterrupt();

//     // Ensure physical line is LOW before arming to prevent immediate false wake
//     if (digitalRead(D2) == HIGH) {
//       Serial.println("Warning: INT1 line still HIGH, clearing latch...");
//       clearMotionInterrupt();
//     }

//     esp_deep_sleep_enable_gpio_wakeup((1ULL << D2), ESP_GPIO_WAKEUP_GPIO_HIGH);
//     Serial.println("State: SETTLED -> Deep sleep indefinitely (Motion wake ONLY, timer disabled).");
//   }

//   // Shut down Wi-Fi peripheral to conserve power
//   if (WiFi.getMode() != WIFI_MODE_NULL) {
//     WiFi.disconnect(true);
//     WiFi.mode(WIFI_OFF);
//   }

//   isolateUnusedPins();

//   unsigned long tTeardownDone = millis();
//   printTimingSummary(tTeardownDone);

//   digitalWrite(WAKE_MARKER_PIN, LOW);

//   Serial.println("Entering deep sleep...\n");
//   Serial.flush();
//   esp_deep_sleep_start();
// }
// static void goToSleepUntilMotion(bool armTimer) {
//   pinMode(D2, INPUT_PULLDOWN);
//   armMotionInterrupt();
//   clearMotionInterrupt();
//   // Verify D2 is LOW before enabling wake source
//   if (digitalRead(D2) == HIGH) {
//     Serial.println("Warning: INT1 still HIGH! Re-clearing filter...");
//     clearMotionInterrupt();
//   }
//   esp_deep_sleep_enable_gpio_wakeup((1ULL << D2), ESP_GPIO_WAKEUP_GPIO_HIGH);

// // deciding wether to arm the timer or not
// // if the chip was still in motion when it went to deep sleep
// // wake up in 25 seconds and calculate, send the position
// if(armTimer){
//    esp_sleep_enable_timer_wakeup((uint64_t)REST_TIMER_S * 1000000ULL);
//     Serial.println("Still moving at sleep time -- also arming 25s recheck timer.");
  
// }
// else{
//    Serial.println("Settled -- motion-only wake, sleeping indefinitely.");
// }
//   // Safely shut down Wi-Fi only if it was turned on
// if (WiFi.getMode() != WIFI_MODE_NULL) {
//     WiFi.disconnect(true);
//     WiFi.mode(WIFI_OFF);
//   }

//   isolateUnusedPins();

//   unsigned long tTeardownDone = millis();
//   printTimingSummary(tTeardownDone);

//   digitalWrite(WAKE_MARKER_PIN, LOW);  // marks "code execution done" for the scope/profiler

//   Serial.println("Going back to sleep. Move the board to wake it.\n");
//   Serial.flush();
//   esp_deep_sleep_start();
// }
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
void loop() {
  // Unused — setup() always ends in deep sleep.
}

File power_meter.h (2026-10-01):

// power_meter.h — INA226 power metering + charge counter for the BLE tracker
// Add as a new tab in the Arduino IDE and #include "power_meter.h" in the main sketch.
// Replaces every INA226 snippet from earlier messages.
#pragma once
#include <Arduino.h>
#include <Wire.h>
#include <sys/time.h>
#include <INA226_WE.h>

// ── Settings ─────────────────────────────────────────────────────────
#define INA226_ADDR        0x40
#define INA_SHUNT_OHMS     0.1f     // R1 on the schematic
#define INA_MAX_AMPS       0.8f     // ±81.92 mV full-scale / 0.1 Ω ≈ 0.82 A
#define I_SLEEP_MA         0.040f   // deep-sleep draw at the BATTERY terminal; measure it
#define BOOT_OVERHEAD_MAH  0.0f     // wake→setup() latency charge; measure with WAKE_MARKER_PIN
#define INA_CORRECTION     1.0f     // scale factor vs your bench meter (ina226.setCorrectionFactor)

// INA226_WE >= 1.3 turned the old enum names (AVERAGE_16, ...) into compile errors and
// requires the INA226_ prefix. Older versions only have the unprefixed names.
#ifdef AVERAGE_16
  #define PM_AVG_16     INA226_AVERAGE_16
  #define PM_CONV_1100  INA226_CONV_TIME_1100
  #define PM_CONT       INA226_CONTINUOUS
#else
  #define PM_AVG_16     AVERAGE_16
  #define PM_CONV_1100  CONV_TIME_1100
  #define PM_CONT       CONTINUOUS
#endif

// ── State ────────────────────────────────────────────────────────────
INA226_WE ina226 = INA226_WE(INA226_ADDR);
static bool g_inaOk = false;

RTC_DATA_ATTR double g_usedMah = 0;            // charge drawn since the counter started
RTC_DATA_ATTR struct timeval g_sleepEnter;     // when we last went to sleep
RTC_DATA_ATTR bool g_haveSleepStamp = false;
static uint32_t g_prevMs = 0;                  // end of the last credited interval
static float    g_sleptS = 0;                  // length of the sleep we just woke from

struct PowerReading {
  float busV = NAN;       // VBUS pin = XIAO side of the shunt
  float battV = NAN;      // cell side = bus + shunt drop
  float currentMa = NAN;
  float powerMw = NAN;
};

// ── Charge counter ───────────────────────────────────────────────────
// The current profile is a staircase, so credit each interval with the reading
// taken at its END (not the average of two readings).
static void meterFeed(float ma) {
  uint32_t now = millis();
  g_usedMah += (double)ma * (now - g_prevMs) / 3600000.0;   // mA·ms → mAh
  g_prevMs = now;
}

// Call first thing in setup(): charges the sleep we just woke from, starts the interval clock.
static void meterWake(uint32_t bootMs) {
  g_prevMs = bootMs;
  g_sleptS = 0;
  if (g_haveSleepStamp) {
    struct timeval nowTv;
    gettimeofday(&nowTv, NULL);
    g_sleptS = (nowTv.tv_sec - g_sleepEnter.tv_sec) + (nowTv.tv_usec - g_sleepEnter.tv_usec) / 1e6f;
    if (g_sleptS < 0) g_sleptS = 0;
    g_usedMah += I_SLEEP_MA * g_sleptS / 3600.0 + BOOT_OVERHEAD_MAH;
  }
}

// ── INA226 ───────────────────────────────────────────────────────────
static bool inaBegin() {
  if (!ina226.init()) return false;
  ina226.setResistorRange(INA_SHUNT_OHMS, INA_MAX_AMPS);
  ina226.setAverage(PM_AVG_16);             // ~35 ms window: smooths WiFi bursts
  ina226.setConversionTime(PM_CONV_1100);
  ina226.setMeasureMode(PM_CONT);
  if (INA_CORRECTION != 1.0f) ina226.setCorrectionFactor(INA_CORRECTION);
  return true;
}

// Bounded wait for the first conversion (the library's own wait has no timeout).
static void inaWaitFirstConversion() {
  if (!g_inaOk) return;
  uint32_t t0 = millis();
  while (ina226.isBusy() && millis() - t0 < 100) delay(1);
}

// Full reading; also feeds the charge counter.
static PowerReading readPower() {
  PowerReading p;
  if (!g_inaOk) return p;
  float shuntMv = ina226.getShuntVoltage_mV();
  p.busV      = ina226.getBusVoltage_V();
  p.battV     = p.busV + shuntMv / 1000.0f;
  p.currentMa = ina226.getCurrent_mA();
  p.powerMw   = ina226.getBusPower();
  meterFeed(p.currentMa);
  return p;
}

// Cheap tick (one register read): call at the END of each constant-current phase.
static void meterTick() {
  if (g_inaOk) meterFeed(ina226.getCurrent_mA());
}

// Call right before isolateUnusedPins() in both sleep functions.
static void meterPrepareSleep() {
  meterTick();                                  // credit the awake time since the last tick
  if (g_inaOk) ina226.powerDown();              // ~2 µA instead of ~330 µA
  gettimeofday(&g_sleepEnter, NULL);
  g_haveSleepStamp = true;
}

// ── JSON helper: print null instead of "nan" (which is invalid JSON) ─
static void jnum(char* out, size_t n, float v, const char* fmt) {
  if (isnan(v)) snprintf(out, n, "null"); else snprintf(out, n, fmt, v);
}

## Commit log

2026-09-02 added 25 s sleep timer when motion detected and infefinte motion awakened sleep ptherwise
2026-09-03 started schematic
    [tracker.kicad_pcb, tracker.kicad_sch]
2026-09-07 added a nmos
    [tracker.kicad_sch]
2026-09-14 added charger files
2026-09-14 added ina226
    [tracker.kicad_sch]
2026-09-15 completed schematic
    [OBJ_INA226 CJMCU-226 BLUE.obj, tracker.kicad_sch]
2026-09-16 adding protection , charging ic
    [tracker.kicad_pcb, tracker.kicad_sch]
2026-09-18 friday update
    [charging_and_battery.kicad_sch, tracker.kicad_pcb, tracker.kicad_sch]
2026-09-18 added led's
    [charging_and_battery.kicad_sch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]
2026-09-18 started routing
    i can do this , 2 planes easy peasy
    [tracker.kicad_pcb]
2026-09-20 more labels on charging
    [charging_and_battery.kicad_sch, tracker.kicad_sch]
2026-09-21 started pcb design
    [charging_and_battery.kicad_sch, tracker.kicad_pcb, tracker.kicad_sch]
2026-09-22 working on ground
    [charging_and_battery.kicad_sch, tracker.kicad_pcb]
2026-09-22 just i drc issue left, maybe push type c a bit forward
    [tracker.kicad_pcb]
2026-09-23 made pcb . bpm , cpl
    [charging_and_battery.kicad_sch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]
2026-09-23 added cpl , bom
    [tracker_JLC_BOM.csv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]
2026-09-24 starting tracker_v2
    [OBJ_INA226 CJMCU-226 BLUE.obj, charging_and_battery.kicad_sch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]
2026-10-01 added header file for power measurement
2026-10-03 started v2 , placement sure routing is being done
    [temp-freerouting.dsn, tracker.kicad_pcb, tracker_v2.kicad_pcb]
2026-10-05 added some connections
    [tracker_v2.kicad_pcb]
2026-10-06 completed v2 routing
    [charging_and_battery.kicad_sch, tracker_v2.kicad_pcb, tracker_v2.kicad_sch]
2026-10-07 removed a GND trace under the chip and connected it to a common ground
    like the title says
    [tracker_v2.kicad_pcb]
2026-10-08 started working on v3
    [OBJ_INA226 CJMCU-226 BLUE.obj, bom.csv, charging_and_battery.kicad_sch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]
2026-10-08 added pogo pins to tracker_v3
    [charging_and_battery.kicad_sch, tracker.kicad_pcb, tracker.kicad_sch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]
2026-10-09 the type c connector is pointing in the wrong direction
    [bom.csv, designators.csv, positions.csv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]
2026-10-12 added through holes
    corrected the type-c charger, battery cable and corrected position of the pogo pins
2026-10-16 added some stuff to schematic
2026-10-19 added diodes
2026-10-19 started pcb v4
2026-10-22 corrected schematic
2026-10-27 added vias and ground plane everywhere
